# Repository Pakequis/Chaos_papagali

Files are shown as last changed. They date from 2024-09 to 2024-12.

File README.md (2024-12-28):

# **Chaos Papagali**

A slightly over-engineered, annoying device that imitates the vibration of a phone.

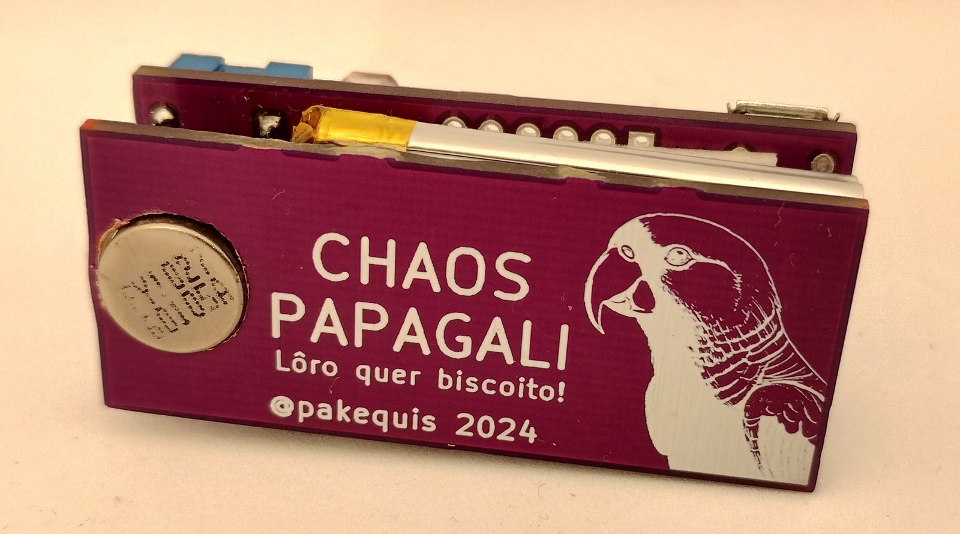
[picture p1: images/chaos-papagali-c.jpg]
Chaos-papagali


## About the project:

This project is an update of the classic electronic cricket circuit that we saw in old electronics magazines. It's a prank device aimed at annoying someone (especially my daughters and my wife). Today, there are devices like the [OpenKobold](https://github.com/Seitanas/OpenKobold) and the [Annoyng PCB](https://annoyingpcb.com/) that play random sounds, but none imitate the vibration of a phone. So, I created one that does.

Chaos Papagali is a little bigger (50 x 21 mm) than Annoyng PCB (44 x 24 mm):
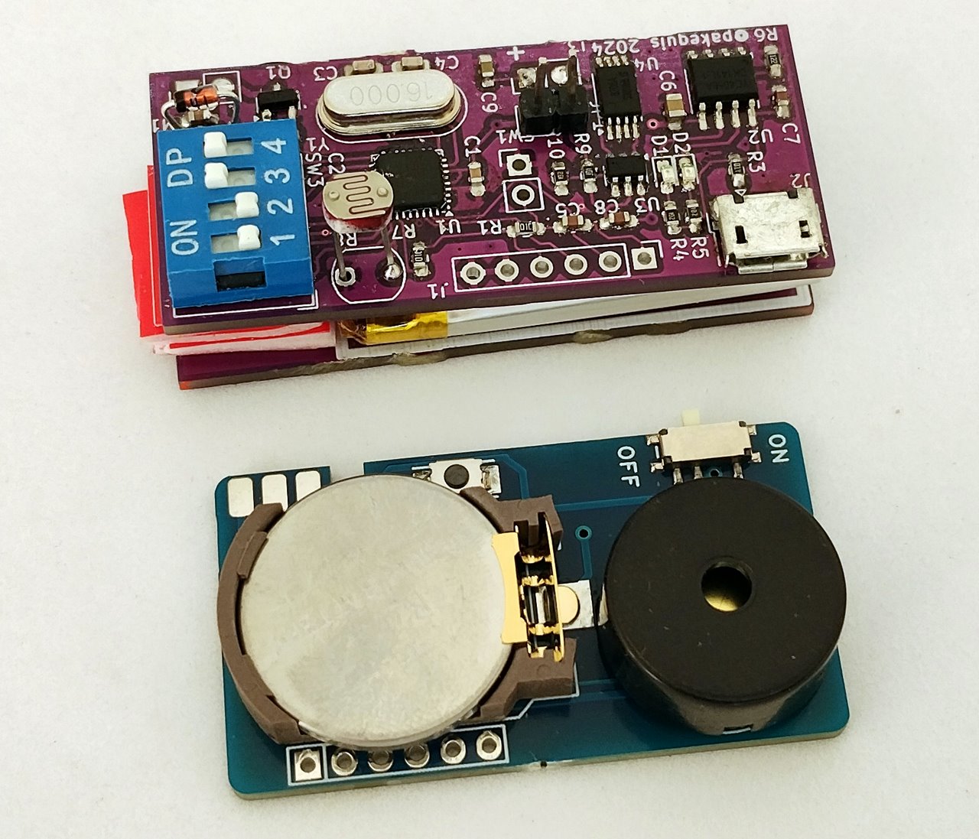
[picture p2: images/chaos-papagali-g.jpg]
Chaos-papagali-comp


In addition to being annoying with its random vibrations, the Chaos Papagali also has the function of only operating in the dark for maximum inconvenience.

## Demo video:
Chaos Papagali demo video (https://www.youtube.com/watch?v=ZlEl3M0w8CY)

## Hardware:

The circuit is a mashup of an Arduino and a battery charger from [OSHWLab](https://oshwlab.com/Little_Arc/TP4056).

The boards were developed in kicad 8.0. There are two PCBs in one panel, one for the circuit and another for support the battery and motor. It is necessary to break the PCB in half during final assembly. The two boards are stacked and secured with double sided tape over the battery.

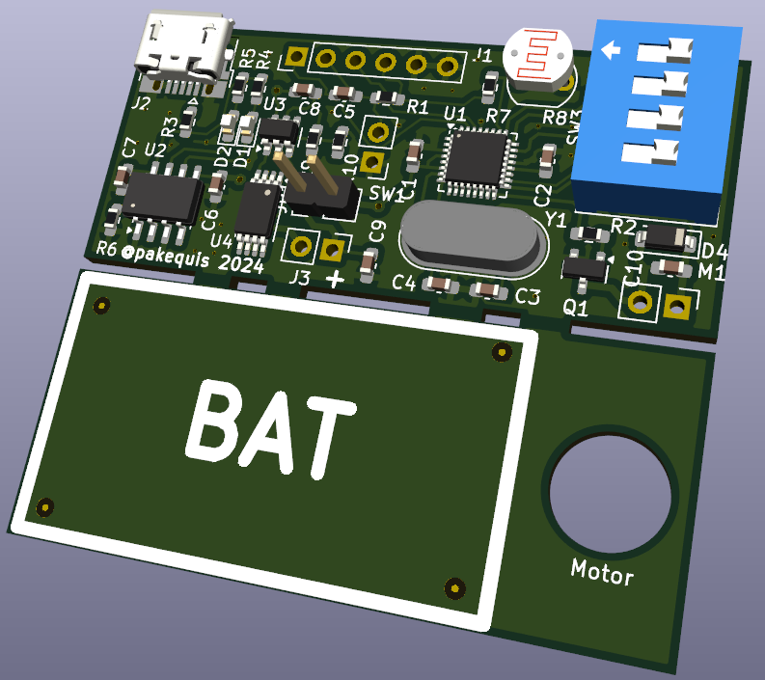
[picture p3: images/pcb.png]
PCB


The project had three phases:

1. Proof of concept assembled with an RGBDuino and a prototyping shield.
2. Prototype using an Arduino Pro Mini and a battery charger module.
3. Final circuit on a two-PCB stack.

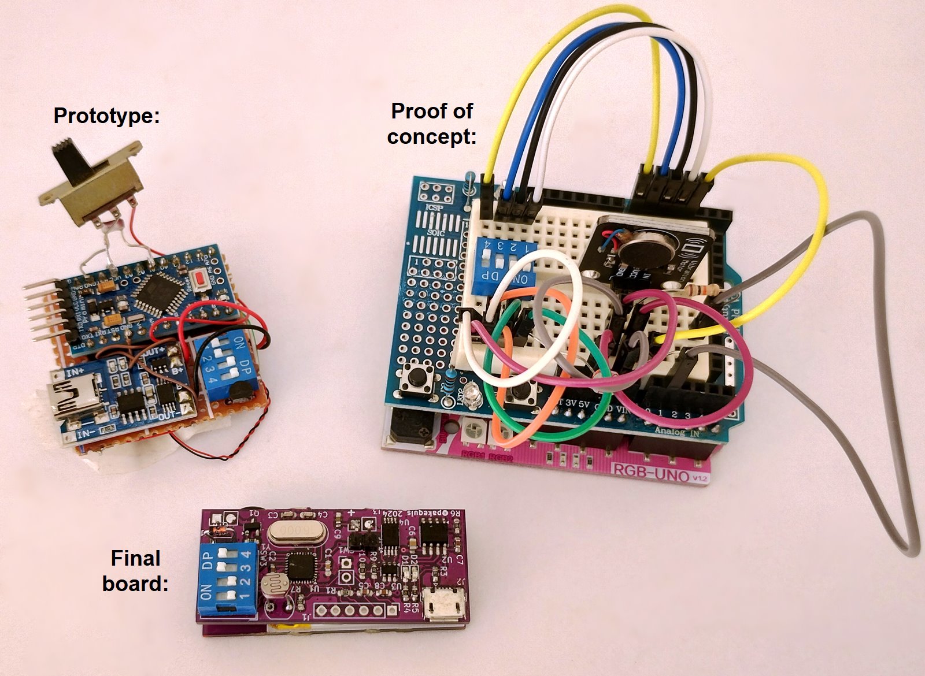
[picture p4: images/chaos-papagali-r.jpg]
Chaos-papagali-phases


The device is powered by a 400 mAh battery and operates with a current consumption of approximately 500 µA in low power mode. This configuration ensures several days of use between charges, depending on the operating interval and the type of motor employed.

The ATMEGA328 microcontroller runs well at 16MHz on battery, although it would be better to lower the frequency using an 8MHz crystal.

## Firmware:
There are two sketches (.ino), one with the main program and another with the functions. 

The firmware goes into low power mode and triggers the vibration motor at random intervals. 

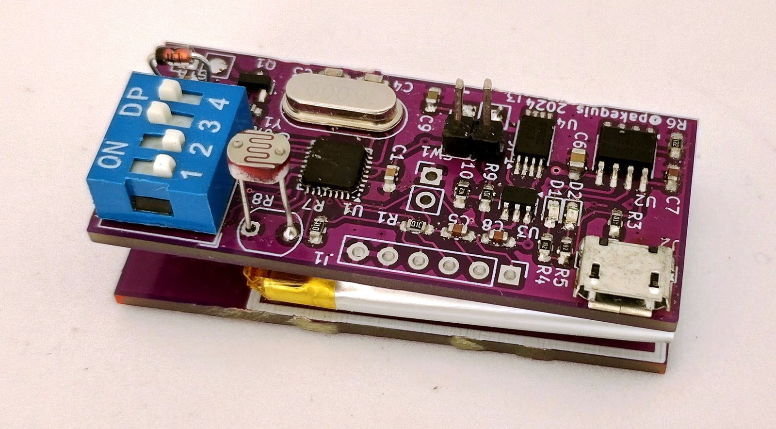
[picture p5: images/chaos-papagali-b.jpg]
Chaos-papagali-circuit


The dip switch selection options:

Dip 1 and 2: Mode of vibration:
    00 = Phone call.
    01 = Phone alarm.
    10 = Phone notification.
    11 = Chaos mode (all modes above, at random).

Dip 3: Day or night function. With 0 the device works with light on the LDR. With 1 the device works only in the dark.

Dip 4: Time short or long. 0 = short time (1 to 10 minutes). 1 = Long time (10 to 60 minutes interval).

## Notes:
1. At first, I considered adding a buzzer to mimic the end-of-cycle sound found in some home appliances. I was able to replicate the beeps of my microwave, but I couldn't manage to imitate those of the washing machine. It seems that washing machine manufacturers opted for a more complex buzzer circuit for some reason.

In these machines, they implement a circuit with frequency and envelope outputs to play classical music (such as "Die Forelle," for example). Since it was taking a long time to develop this part, I decided to remove the buzzer from the project.

2. In some cases, it is necessary to secure the PCB to the surface with adhesive tape or by placing a weight on it; otherwise, it may 'walk' on the surface.

3. Image of a parrot (Papagali in Romanian) generated with AI, because I don't have the gift for drawing. The project name is a reference to that [song](https://www.youtube.com/watch?v=nYc09Xqy3hE) by the second greatest metal band in the world.

4. Is possible to make this with a couple of LM555? Maybe...

## Contact:
Feel free to reach out to me on social media: @pakequis in any of them...

You can also send me an email at pakequis (at Gmail).

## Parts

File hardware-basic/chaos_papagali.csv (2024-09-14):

Reference | Value | Datasheet | Footprint | Qty | DNP
C1,C2,C5,C8,C10 | 0.1uF | ~ | Capacitor_SMD:C_0603_1608Metric_Pad1.08x0.95mm_HandSolder | 5
C3,C4 | 12pF | ~ | Capacitor_SMD:C_0603_1608Metric_Pad1.08x0.95mm_HandSolder | 2
C6,C7,C9 | 10uF | ~ | Capacitor_SMD:C_0603_1608Metric_Pad1.08x0.95mm_HandSolder | 3
D1 | PWR | ~ | LED_SMD:LED_0603_1608Metric_Pad1.05x0.95mm_HandSolder | 1
D2 | CHRG | ~ | LED_SMD:LED_0603_1608Metric_Pad1.05x0.95mm_HandSolder | 1
D4 | 1N4148W | https://www.vishay.com/docs/85748/1n4148w.pdf | Diode_SMD:D_SOD-123 | 1
F1,F2,F3,F4 | Fiducial | ~ | Fiducial:Fiducial_0.5mm_Mask1.5mm | 4
J1 | Conn_01x06 | ~ | Connector_PinHeader_2.54mm:PinHeader_1x06_P2.54mm_Vertical | 1 | DNP
J2 | USB_B_Micro | ~ | Connector_USB:USB_Micro-B_Amphenol_10103594-0001LF_Horizontal | 1
J3 | BAT | ~ | Connector_PinHeader_2.54mm:PinHeader_1x02_P2.54mm_Vertical | 1 | DNP
JP1 | jumper | ~ | Connector_PinHeader_2.54mm:PinHeader_1x02_P2.54mm_Vertical | 1
M1 | Motor_DC | ~ | Connector_PinHeader_2.54mm:PinHeader_1x02_P2.54mm_Vertical | 1 | DNP
Q1 | BC847 | http://www.infineon.com/dgdl/Infineon-BC847SERIES_BC848SERIES_BC849SERIES_BC850SERIES-DS-v01_01-en.pdf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 | Package_TO_SOT_SMD:SOT-23 | 1
R1,R7 | 10k | ~ | Resistor_SMD:R_0603_1608Metric_Pad0.98x0.95mm_HandSolder | 2
R2 | 4.7k | ~ | Resistor_SMD:R_0603_1608Metric_Pad0.98x0.95mm_HandSolder | 1
R3 | 1R | ~ | Resistor_SMD:R_0603_1608Metric_Pad0.98x0.95mm_HandSolder | 1
R4,R5 | 1.6k | ~ | Resistor_SMD:R_0603_1608Metric_Pad0.98x0.95mm_HandSolder | 2
R6 | 1.2k | ~ | Resistor_SMD:R_0603_1608Metric_Pad0.98x0.95mm_HandSolder | 1
R8 | LDR07 | http://www.tme.eu/de/Document/f2e3ad76a925811312d226c31da4cd7e/LDR07.pdf | OptoDevice:R_LDR_5.1x4.3mm_P3.4mm_Vertical | 1
R9 | 100 | ~ | Resistor_SMD:R_0603_1608Metric_Pad0.98x0.95mm_HandSolder | 1
R10 | 1k | ~ | Resistor_SMD:R_0603_1608Metric_Pad0.98x0.95mm_HandSolder | 1
SW1 | SW_Push | ~ | Connector_PinHeader_2.54mm:PinHeader_1x02_P2.54mm_Vertical | 1 | DNP
SW3 | SW_DIP_x04 | ~ | Button_Switch_THT:SW_DIP_SPSTx04_Slide_9.78x12.34mm_W7.62mm_P2.54mm | 1
U1 | ATmega328P-M | http://ww1.microchip.com/downloads/en/DeviceDoc/ATmega328_P%20AVR%20MCU%20with%20picoPower%20Technology%20Data%20Sheet%2040001984A.pdf | Package_DFN_QFN:QFN-32-1EP_5x5mm_P0.5mm_EP3.1x3.1mm | 1
U2 | TP4056 |  | Package_SO:SOP-8_3.9x4.9mm_P1.27mm | 1
U3 | ~ |  | Package_TO_SOT_SMD:SOT-23-6 | 1
U4 | FS8205A |  | Package_SO:TSSOP-8_4.4x3mm_P0.65mm | 1
Y1 | 16MHz | ~ | Crystal:Crystal_HC49-U_Vertical | 1

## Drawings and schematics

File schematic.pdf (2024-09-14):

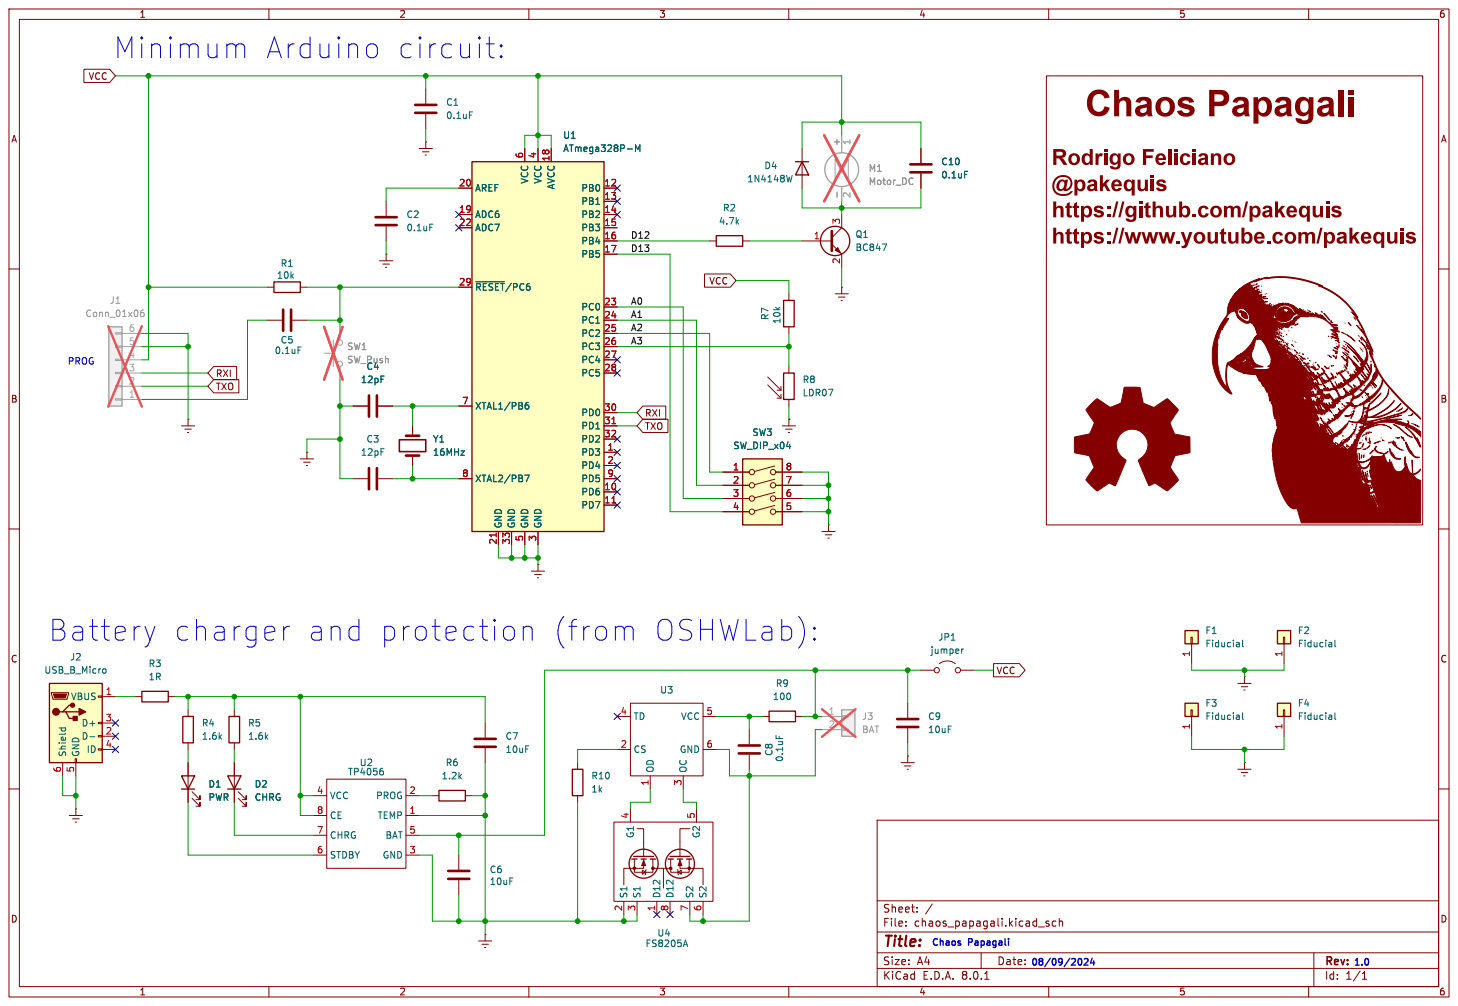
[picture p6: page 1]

Rodrigo Feliciano
@pakequis
https://github.com/pakequis
https://www.youtube.com/pakequis

Id: 1/1 Title: File: chaos_papagali.kicad_sch Sheet: / JP1

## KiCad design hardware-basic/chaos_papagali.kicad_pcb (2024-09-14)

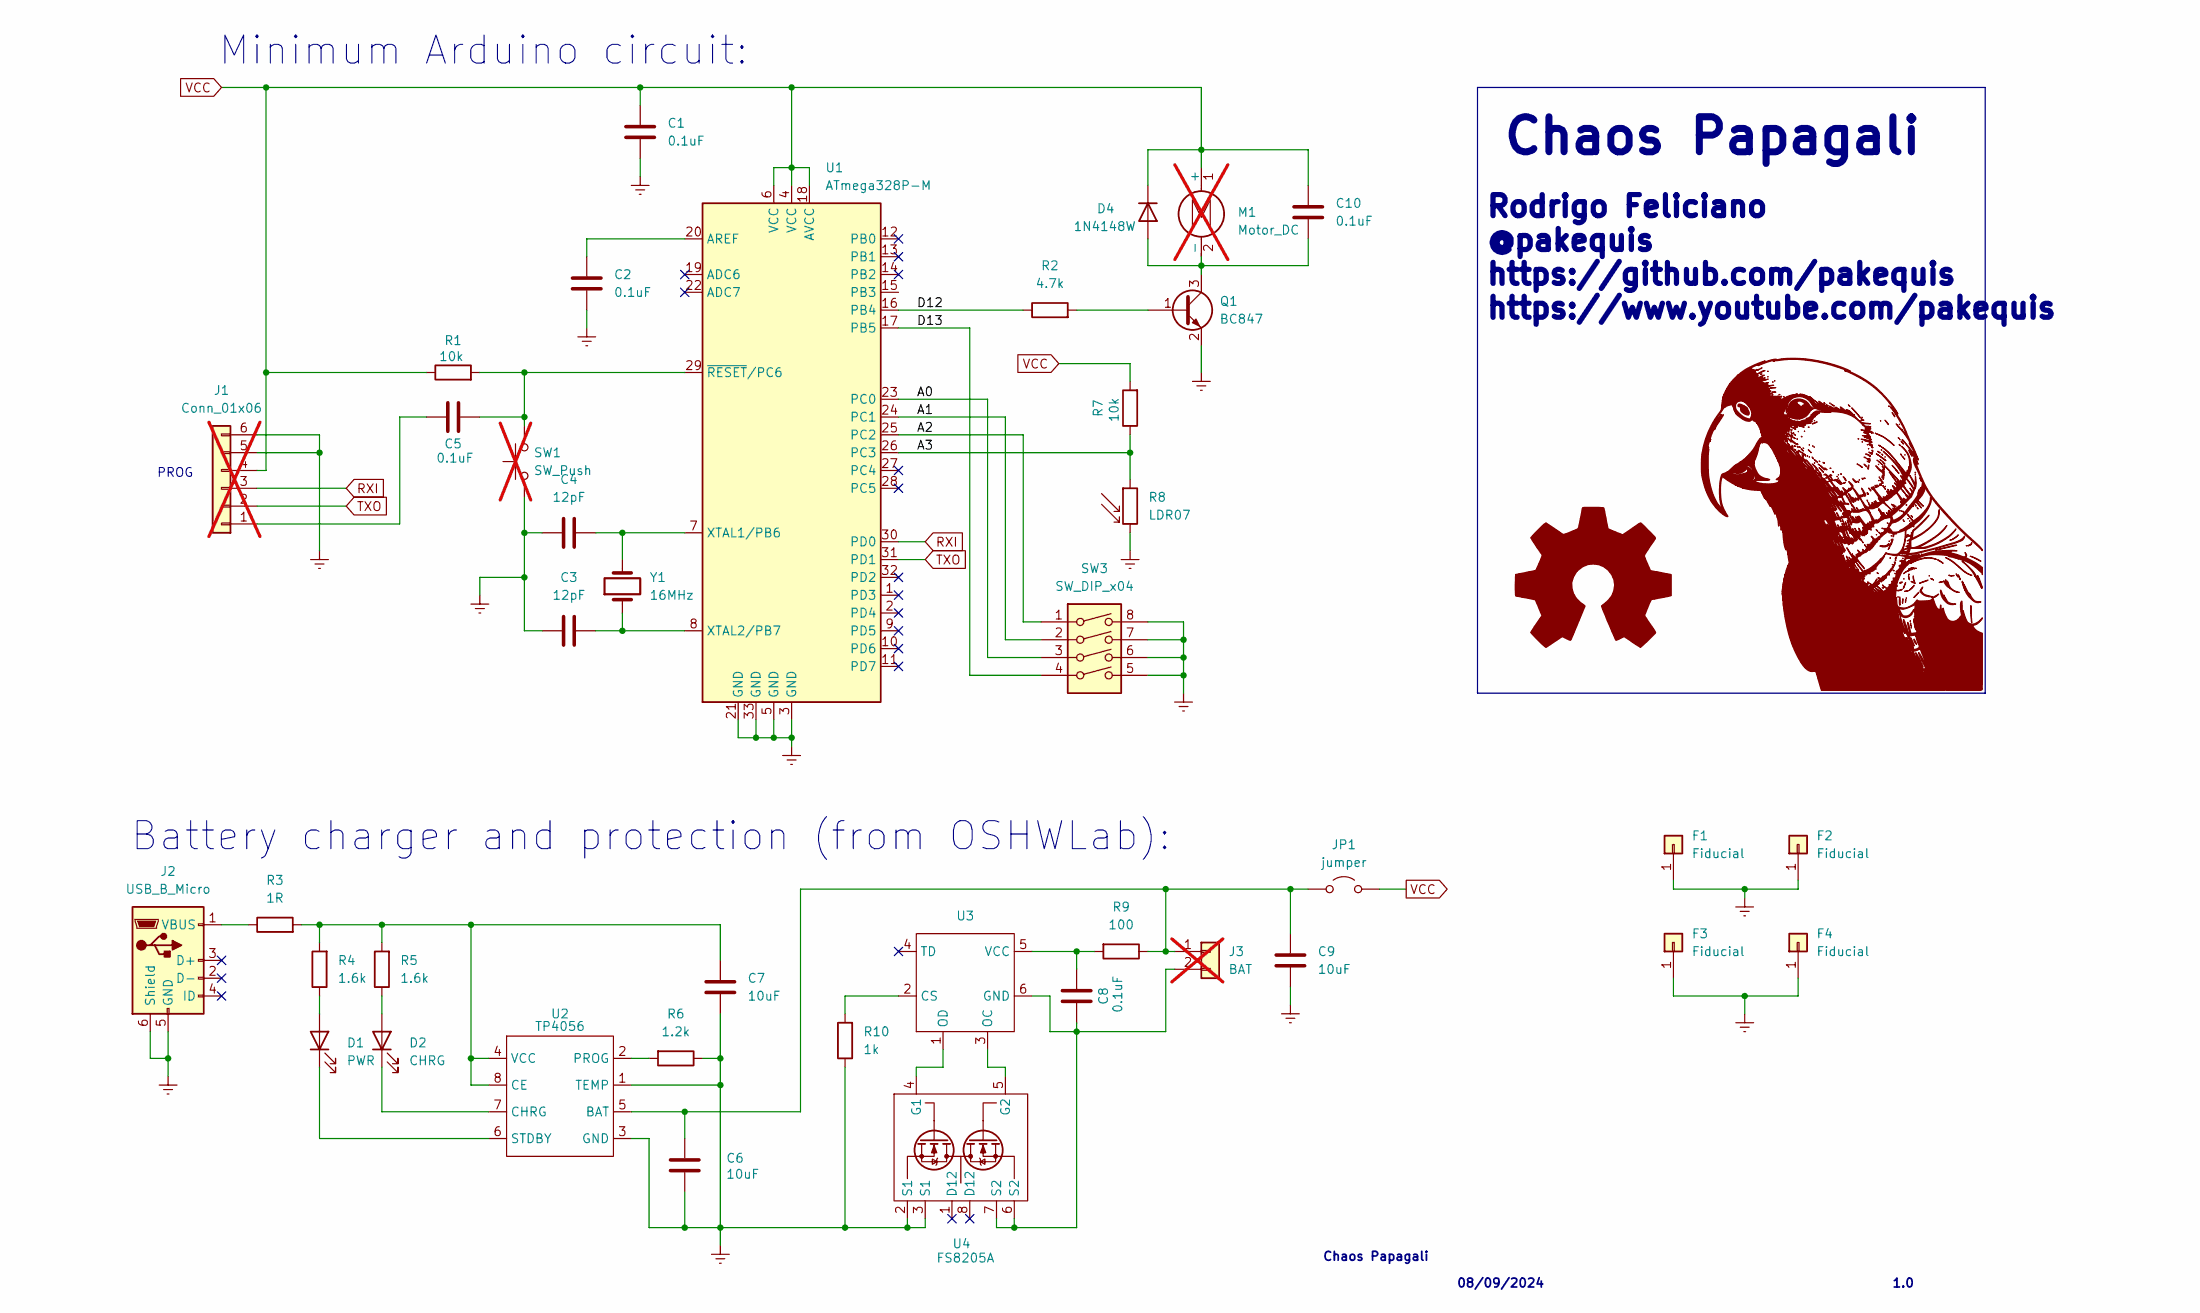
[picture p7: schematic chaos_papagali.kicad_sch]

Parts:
C1, C2, C5, C8, C10: 0.1uF; C_0603_1608Metric_Pad1.08x0.95mm_HandSolder
C3, C4: 12pF; C_0603_1608Metric_Pad1.08x0.95mm_HandSolder
C6, C7, C9: 10uF; C_0603_1608Metric_Pad1.08x0.95mm_HandSolder
D1: PWR; LED_0603_1608Metric_Pad1.05x0.95mm_HandSolder
D2: CHRG; LED_0603_1608Metric_Pad1.05x0.95mm_HandSolder
D4: 1N4148W; D_SOD-123
F1, F2, F3, F4: Fiducial; Fiducial_0.5mm_Mask1.5mm
J1: Conn_01x06; PinHeader_1x06_P2.54mm_Vertical; not fitted
J2: USB_B_Micro; USB_Micro-B_Amphenol_10103594-0001LF_Horizontal
J3: BAT; PinHeader_1x02_P2.54mm_Vertical; not fitted
JP1: jumper; PinHeader_1x02_P2.54mm_Vertical
M1: Motor_DC; PinHeader_1x02_P2.54mm_Vertical; not fitted
Q1: BC847; SOT-23
R1, R7: 10k; R_0603_1608Metric_Pad0.98x0.95mm_HandSolder
R2: 4.7k; R_0603_1608Metric_Pad0.98x0.95mm_HandSolder
R3: 1R; R_0603_1608Metric_Pad0.98x0.95mm_HandSolder
R4, R5: 1.6k; R_0603_1608Metric_Pad0.98x0.95mm_HandSolder
R6: 1.2k; R_0603_1608Metric_Pad0.98x0.95mm_HandSolder
R8: LDR07; R_LDR_5.1x4.3mm_P3.4mm_Vertical
R9: 100; R_0603_1608Metric_Pad0.98x0.95mm_HandSolder
R10: 1k; R_0603_1608Metric_Pad0.98x0.95mm_HandSolder
SW1: SW_Push; PinHeader_1x02_P2.54mm_Vertical; not fitted
SW3: SW_DIP_x04; SW_DIP_SPSTx04_Slide_9.78x12.34mm_W7.62mm_P2.54mm
U1: ATmega328P-M; QFN-32-1EP_5x5mm_P0.5mm_EP3.1x3.1mm
U2: TP4056; SOP-8_3.9x4.9mm_P1.27mm
U3: SOT-23-6
U4: FS8205A; TSSOP-8_4.4x3mm_P0.65mm
Y1: 16MHz; Crystal_HC49-U_Vertical

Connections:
/A3: R7.1, R8.1, U1.26 (PC3)
/D5: SW3.2, U1.24 (PC1)
/D6: SW3.3, U1.23 (PC0)
/D7: SW3.4, U1.17 (PB5)
/D12: R2.1, U1.16 (PB4)
GNDREF: C1.2, C2.2, C3.1, C4.1, C6.1, C7.1, C9.1, F1.1, F2.1, F3.1, F4.1, J1.5, J1.6, J2.5 (GND), J2.6 (Shield), Q1.2 (E), R6.1, R8.2, R10.1, SW1.1, SW3.5, SW3.6, SW3.7, SW3.8, U1.3 (GND), U1.5 (GND), U1.21 (GND), U1.33 (GND), U2.1 (TEMP), U2.3 (GND), U4.2 (S1), U4.3 (S1)
unnamed: D1.2 (A), R4.1
unnamed: D1.1 (K), U2.6 (STDBY)
unnamed: D2.2 (A), R5.1
unnamed: D2.1 (K), U2.7 (CHRG)
unnamed: C10.2, D4.2 (A), M1.2 (-), Q1.3 (C)
unnamed: C5.1, J1.1
unnamed: J2.1 (VBUS), R3.1
unnamed: C6.2, C9.2, J3.1, JP1.1 (A), R9.1, U2.5 (BAT)
unnamed: C8.1, J3.2, U3.6 (GND), U4.6 (S2), U4.7 (S2)
unnamed: Q1.1 (B), R2.2
unnamed: C2.1, U1.20 (AREF)
unnamed: SW3.1, U1.25 (PC2)
unnamed: C4.2, U1.7 (XTAL1/PB6), Y1.2
unnamed: C3.2, U1.8 (XTAL2/PB7), Y1.1
unnamed: C5.2, R1.2, SW1.2, U1.29 (~RESET/PC6)
unnamed: C7.2, R3.2, R4.2, R5.2, U2.4 (VCC), U2.8 (CE)
unnamed: R6.2, U2.2 (PROG)
unnamed: R10.2, U3.2 (CS)
unnamed: U3.3 (OC), U4.5 (G2)
unnamed: U3.1 (OD), U4.4 (G1)
unnamed: C8.2, R9.2, U3.5 (VCC)
RXI: J1.3, U1.30 (PD0)
TXO: J1.2, U1.31 (PD1)
VCC: C1.1, C10.1, D4.1 (K), J1.4, JP1.2 (B), M1.1 (+), R1.1, R7.2, U1.4 (VCC), U1.6 (VCC), U1.18 (AVCC)

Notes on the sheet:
Chaos Papagali
Battery charger and protection (from OSHWLab):
Minimum Arduino circuit:
08/09/2024
Rodrigo Feliciano @pakequis https://github.com/pakequis https://www.youtube.com/pakequis
PROG
1.0

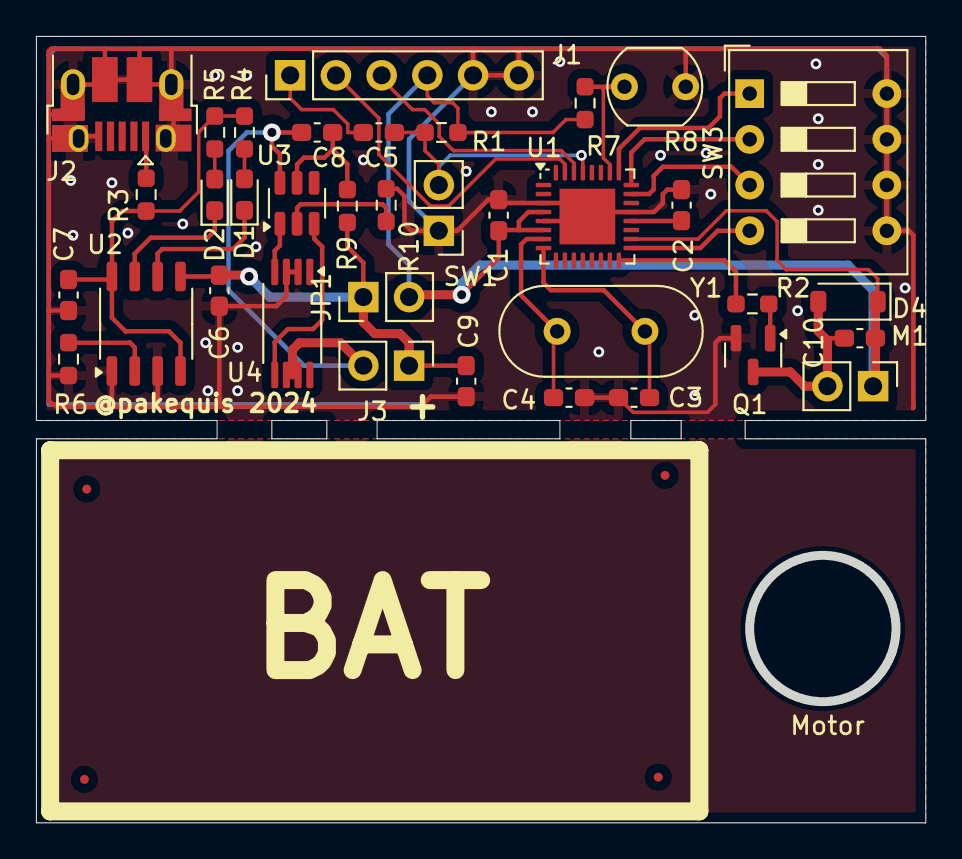
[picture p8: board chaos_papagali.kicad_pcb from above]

Board: 2 copper layers, 49.4 x 43.7 mm, 40 parts (0 on the bottom side), 30 nets.

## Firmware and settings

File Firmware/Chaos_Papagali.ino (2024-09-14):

/*
  CHAOS PAPAGALI
  Lôro quer biscoito!
  by Rodrigo Feliciano
  https://www.youtube.com/pakequis
  https://www.pakequis.com.br
*/

#include <LowPower.h>

#define MODE0   0
#define MODE1   1
#define MODE2   2
#define MODE3   3

/*************************/
/* Arduino Uno R3 - Proof of concept */
//#define MOTOR_PIN   3
//#define SW1   4
//#define SW2   5
//#define SW3   6
//#define SW4   7
//#define LIGHT_SENSOR_PIN 1
/*************************/

/*************************/
/* Arduino Pro mini - Prototype */
//#define MOTOR_PIN   9
//#define SW1   5
//#define SW2   4
//#define SW3   3
//#define SW4   2
//#define LIGHT_SENSOR_PIN 1
/*************************/

/******************************/
/* Chaos Papagali final board */
#define MOTOR_PIN   12
#define SW1   A2
#define SW2   A1
#define SW3   A0
#define SW4   13
#define LIGHT_SENSOR_PIN A3
/*************************/

#define LIGHT_THRESHOLD  450

/* time = random number x8 seconds */
#define TIME_MIN  8   /* 64 seconds */
#define TIME_MID  75  /* 600 seconds = 10 minutes */
#define TIME_MAX  450 /* 3600 seconds = 1 hour */

struct chaos_mode{
  uint8_t chmode;           /* 0 to 3 modes */
  bool day_or_night;        /* 0 = Day, 1 = night */
  bool time_short_or_long;  /* 0 = 1 to 10 minutes, 1 = 10 to 60 minutes */
};

struct chaos_mode modes;

int chaos_time = 0;
int light_value = 0;

void setup() 
{
 // Serial.begin(9600); //for debug only
  pinMode(MOTOR_PIN, OUTPUT);

  randomSeed(analogRead(A3));
  
  pinMode(SW1, INPUT_PULLUP);
  pinMode(SW2, INPUT_PULLUP);
  pinMode(SW3, INPUT_PULLUP);
  pinMode(SW4, INPUT_PULLUP);

  check_mode(&modes);

 // Serial.println(modes.chmode);

  if(modes.time_short_or_long == 1)
  {
    chaos_time = random(TIME_MID, TIME_MAX);  /* 600 to 3600 seconds */
  }else
  {
    chaos_time = random(TIME_MIN, TIME_MID); /* 64 to 600 seconds */
  }

  digitalWrite(MOTOR_PIN, LOW);
}

void loop() 
{
  light_value = analogRead(LIGHT_SENSOR_PIN);
  /* Execute one chaos mode */
  check_mode(&modes);  
    
  if(((light_value > LIGHT_THRESHOLD) && (modes.day_or_night)) || ((light_value < LIGHT_THRESHOLD) && (!(modes.day_or_night))))
  {
    switch (modes.chmode)
    {
      case MODE0:
        mode_phone_call();
        //Serial.println("Phone Call");
      break;
    
      case MODE1:
        mode_alarm();
        //Serial.println("Alarm");
      break;  
      
      case MODE2:
        mode_notification();
        //Serial.println("Notification");
      break;

      case MODE3:
        mode_chaos();
        //Serial.println("Chaos");
      break;
   
      default:    
    
      break;
    }
  }

  /* Check the random time (short or long) */
  if(modes.time_short_or_long == 1)
  {
    chaos_time = random(TIME_MID, TIME_MAX);  /* 600 to 3600 seconds */
  }else
  {
    chaos_time = random(TIME_MIN, TIME_MID); /* 64 to 600 seconds */
  }

//for debug only
/*  Serial.println(light_value);
  Serial.println(modes.chmode);
  Serial.println(modes.day_or_night);
  Serial.println(modes.time_short_or_long);
  Serial.print("random = ");
  Serial.println(chaos_time);
  delay(100);            */

  /* Wait in low power mode */
  for(int p = 0; p < chaos_time; p++)
  {
    LowPower.powerDown(SLEEP_8S, ADC_OFF, BOD_OFF);  /* 500 uA in this mode  */
  }
}

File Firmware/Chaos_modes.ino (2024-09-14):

/*
  CHAOS PAPAGALI
  Lôro quer biscoito!
  by Rodrigo Feliciano
  https://www.youtube.com/pakequis
  https://www.pakequis.com.br
*/

/* Check dip switch config */
void check_mode(chaos_mode *cm)
{
  cm->chmode = 0;
  bitWrite(cm->chmode, 0, digitalRead(SW1));
  bitWrite(cm->chmode, 1, digitalRead(SW2));

  cm->day_or_night = digitalRead(SW3);
  cm->time_short_or_long = digitalRead(SW4);
}


/* phone call (1250ms ON, 1000ms off */
void mode_phone_call(void)
{
  for (int i = 0; i < 4; i++)
  {
    digitalWrite(MOTOR_PIN, 1);
    delay(1250);
    digitalWrite(MOTOR_PIN, 0);
    delay(1000); 
  }
}

/* Phone alarm (500ms on, 500ms off */  
void mode_alarm(void)
{
  for (int i = 0; i < 5; i++)
  {
    digitalWrite(MOTOR_PIN, 1);
    delay(500);
    digitalWrite(MOTOR_PIN, 0);
    delay(500); 
  }
}

/* Phone notification */
void mode_notification(void)
{
  digitalWrite(MOTOR_PIN, 1);
  delay(250);
  digitalWrite(MOTOR_PIN, 0);
  delay(100);   
  digitalWrite(MOTOR_PIN, 1);
  delay(250);
  digitalWrite(MOTOR_PIN, 0);
  delay(100);   
}

/* All modes */
void mode_chaos(void)
{
  int rnd_mode = random(0,4);
  switch (rnd_mode)
  {  
    case MODE0:   /* 20% */
      mode_phone_call();
    break;
      
    case MODE1:
      mode_alarm(); /* 20% */
    break;
      
    default:    /* Notification with 60% chance */ 
      mode_notification();
    break;
  }
}
